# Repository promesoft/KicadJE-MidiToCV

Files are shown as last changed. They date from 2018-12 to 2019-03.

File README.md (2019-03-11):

# Kicad-MidiToCV
Midi to CV in Eurorack or as standalone

## Status - Rev B - Ongoing PCB layout and Sch update
Set on hold - MK2 is in progress ATM
## Status - Rev A Mounted - Midi code in progress
| Stage  | Detail | Status |
| --- | --- | --- |
| create material  | sch/pcb | produced Rev A  |
| | gerber | produced and uploaded RevA |
| production  | ordered  | OK |
|  | produced | OK |
|  | delivered | OK |
| ------------- | ------------- | ------------- |
| SOFTWARE | LFO | OK |
| SOFTWARE | MIDI MAP | OK - Stage 1 |
| SOFTWARE | CV | Ongoing |

## Preliminary validation
| Test  | Detail | Status |
| --- | --- | --- |
| Initial Inspection | Visual - Component Mounting | NOT OK |
| Initial Technical Test | Base operation | MIDI OUT NOT OK |
| | Knobs | OK |
| Initial Technical Test | MIDI IN | OK |
| Initial Technical Test | MIDI OUT | OK (to USB adapter) |
| Initial Product Test | MIDI IN/OUT MAPPER| OK |
| Initial Product Test | MIDI IN / CV OUT / GATE OUT| OK |
| Initial Product Test | LFO OUT| OK (use different pinout) |

## Secondary validation
| Test  | Detail | Status |
| --- | --- |--- |
| Product Test | MIDI IN/OUT| OUT - FAIL on Roland keyboard |
| Product Test | LFO on DIO6 and 9 with ext RC | OK ! |
| Quality | LFO | Very usable |
| Quality | MIDI IN | |
| Quality | MIDI to CV | |
| Quality | MIDI to GATE | |
| Long Term Product Test | MIDI IN |  |
| Long Term Product Test | CV OUT |  |
| Long Term Product Test | GATE OUT |  |
| Long Term Product Test | LFO OUT | OK |
### Issues and Notes
Please note that the PIN1 and PIN2 are GATE. This is note described clearly in http://www.doepfer.de/a100_man/a100t_e.htm and needs to be noted when soldering the IDC header or when cabling if a Pin header has been mounted.
 * The two pots on the breakout board are too close for adding a knob
 * The orientation of the pinheader for the MCP4725 module - if mounted incorrectly the magic smoke disappears
 * 0R could be replaced with SMD jumpers
 * Consider a 200 mA fuse for Vin and 50mA for +5V pwr
 * The mounting hole that is off center is not matching both boards
### Errata
 * Footprint of PJ-321 has too small drill holes (1mm) - major
 * Footprint of PJ-321 is too narrow in the rear end :) - minor issue
 * Midi out circuit is WRONG - Major
### Workarounds
* Midi out not working - PCB workaround mod partially possible for voltage controlled inputs.
 * --Remove GND around DIN pin 5 (bottom copper side)
 * --Cut GND track to DIN pin 5 (top copper side)
 * --Remove Q1, R6, R9
 * --Connect 220R THT to base pad on Q1
 * --Connect C and E on Q1
 * --Add GND wire to pin2 of MIDI out DIN
## Physical Construction
 - 100x100mm
 - Separate unit with no alteration
 - Optional split in 2 for eurorack mount mirrored config

## Vital Components
 - Arduino Nano - where the magic lives (remember to socket it to be able to reprogram it)
 - Jack connectors: PJ-321 (important for the footprint)
 - KY-40 Encoder module (important for the pullup, footprint and 3D alignment)
 - MCP4825 module - if chosen (important for CV out function - footprint needs to match)
 If these are chosen the last two CV jacks should be ommitted.
 - MCP4728 chip - if chosen (important for the last 2 CV out)

## MIDI Board Features
### Single board - MIDI I/O and MIDI to CV
The board can be used as is for a prototype development of MIDI to CV
### Split board Eurorack - MIDI I/O and MIDI to CV
The board can be devided in two and combined front to front with spacers for a MIDI to CV eurorack module.
### Base board Eurorack - MIDI I/O
If only MIDI features are required the base board can work without the IO section.

## Generic Board Features
### Split board Options
The main board (with the arduino) has a couple of headers that can be connected to a different interface board using I2C, Analogue Inputs and Digital I/O.
### Non MIDI board
The MIDI components can be omitted if the features does not require MIDI, like an LFO, VCO or ADSR circuit.

## Base Construction
Arduino Nano based Controller and MIDI decoder.

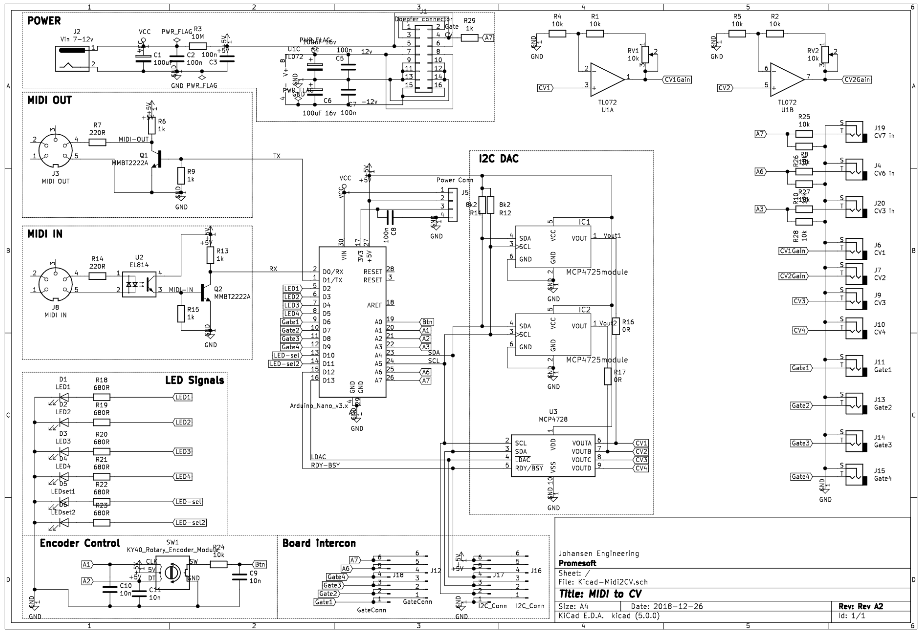
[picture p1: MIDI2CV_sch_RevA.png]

### MIDI In
MIDI In through a PC814 (or optional PC817) Optocoupler and into the RX pin on the Arduino

### Midi Out
Optional expansion

### Gate
Gate pins from Arduino

## CV Out
I2C Dac with 2 options
### I2C Dac - Option 1 - Two Single channel DAC
2x MCP4725 DAC 
### I2C Dac - Option 2 - One 4 channel DAC
1x MCP4728

# RevB
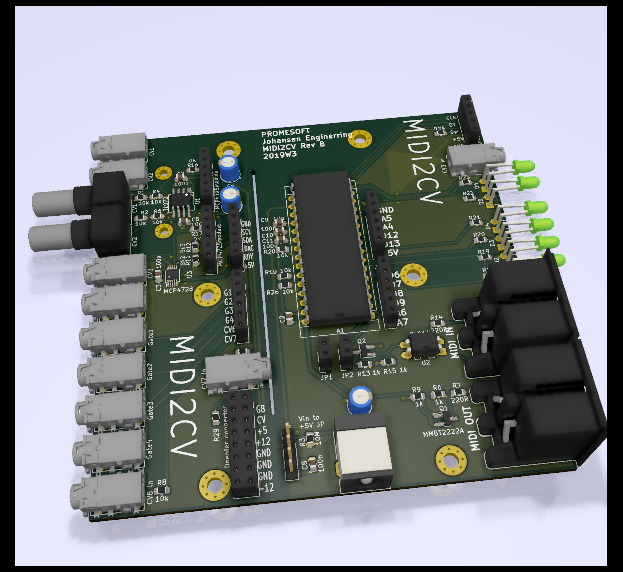
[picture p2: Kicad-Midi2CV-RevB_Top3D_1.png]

# RevA
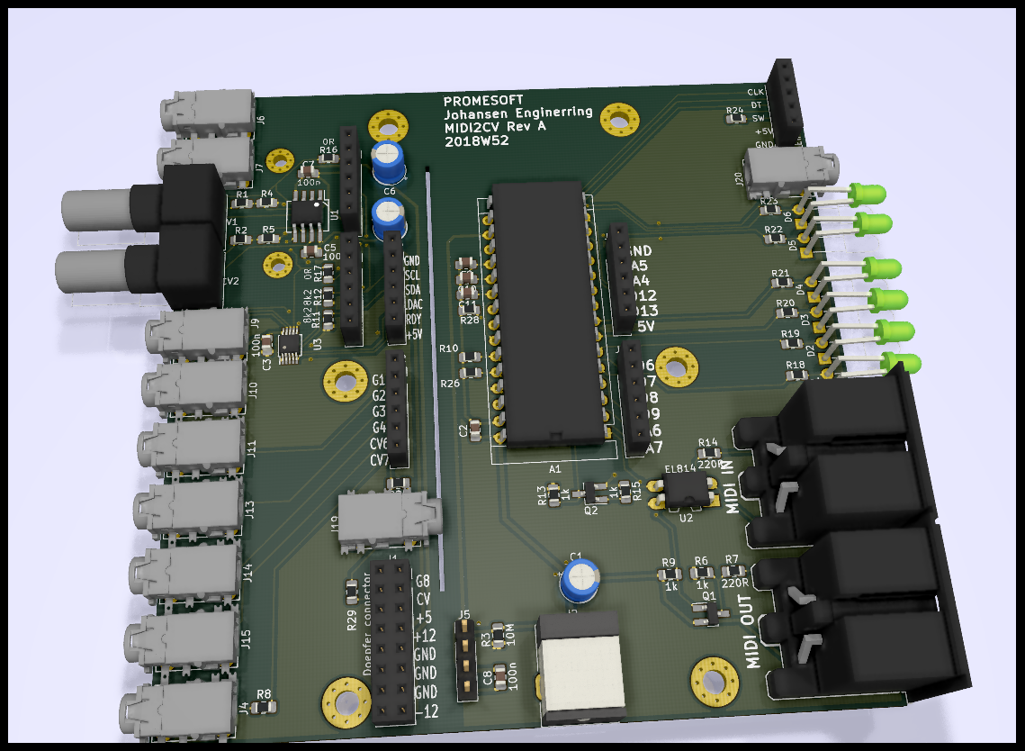
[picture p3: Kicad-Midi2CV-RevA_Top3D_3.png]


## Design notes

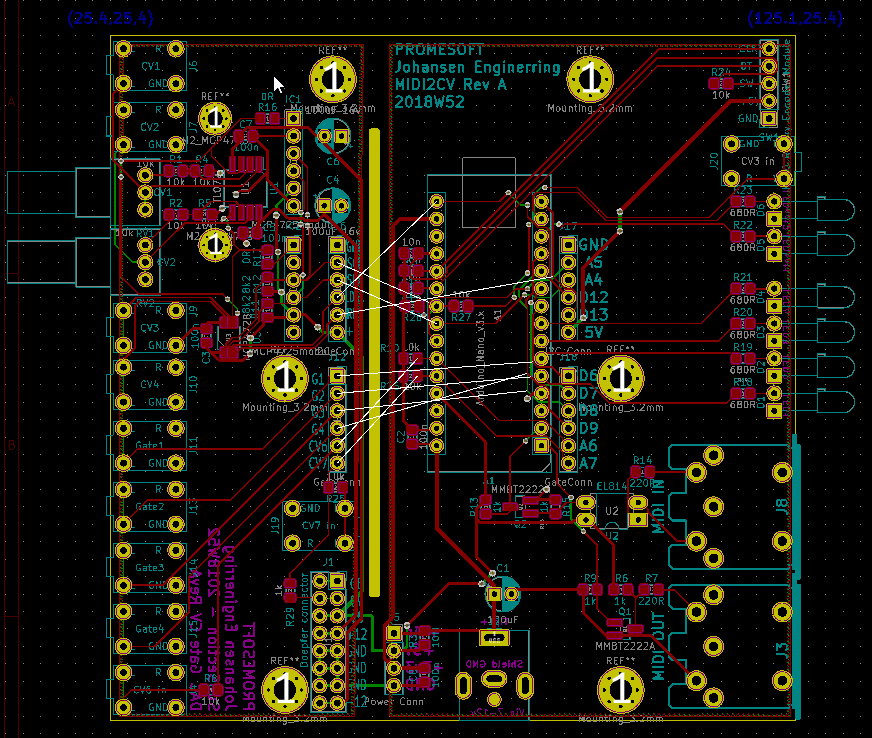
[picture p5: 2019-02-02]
2019-01-02 23_18_55-Window.png

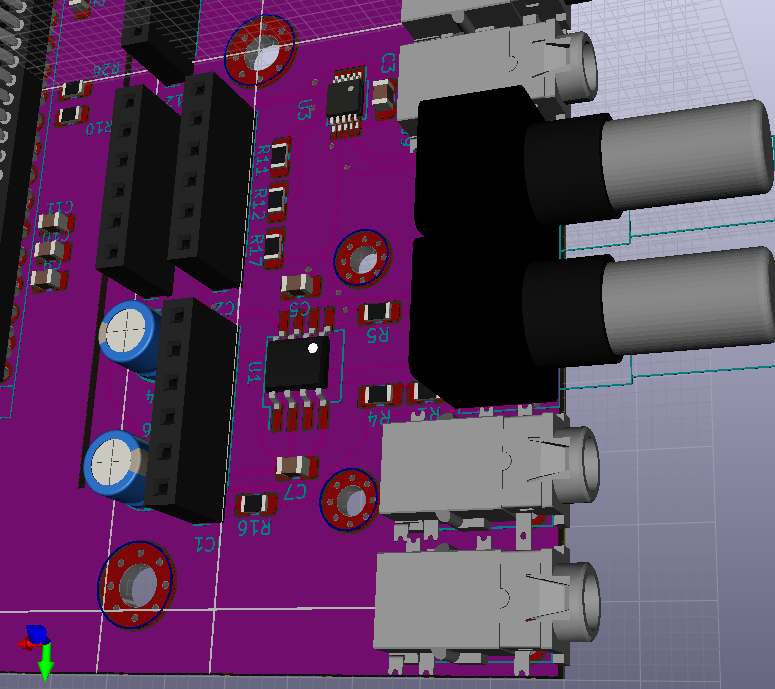
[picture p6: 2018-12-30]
RevA/MIDI2CV.png

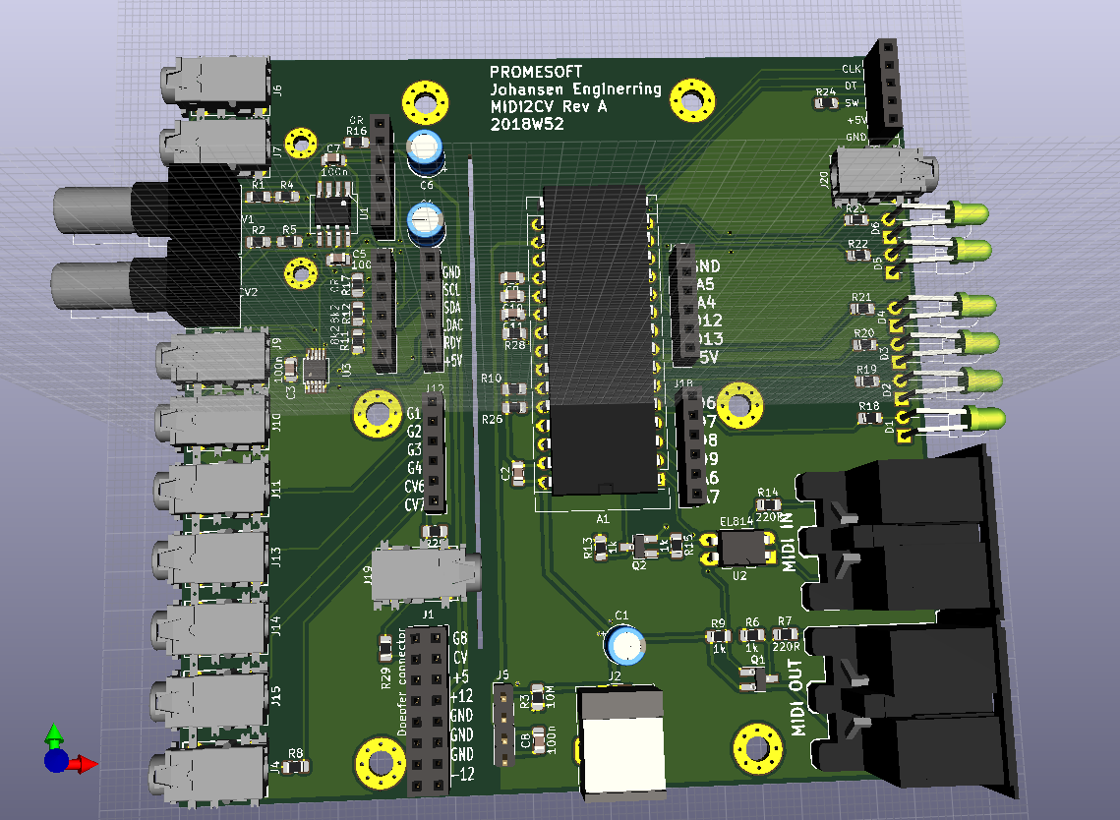
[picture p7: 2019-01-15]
RevA/Kicad-Midi2CV-RevA_Top3D.png

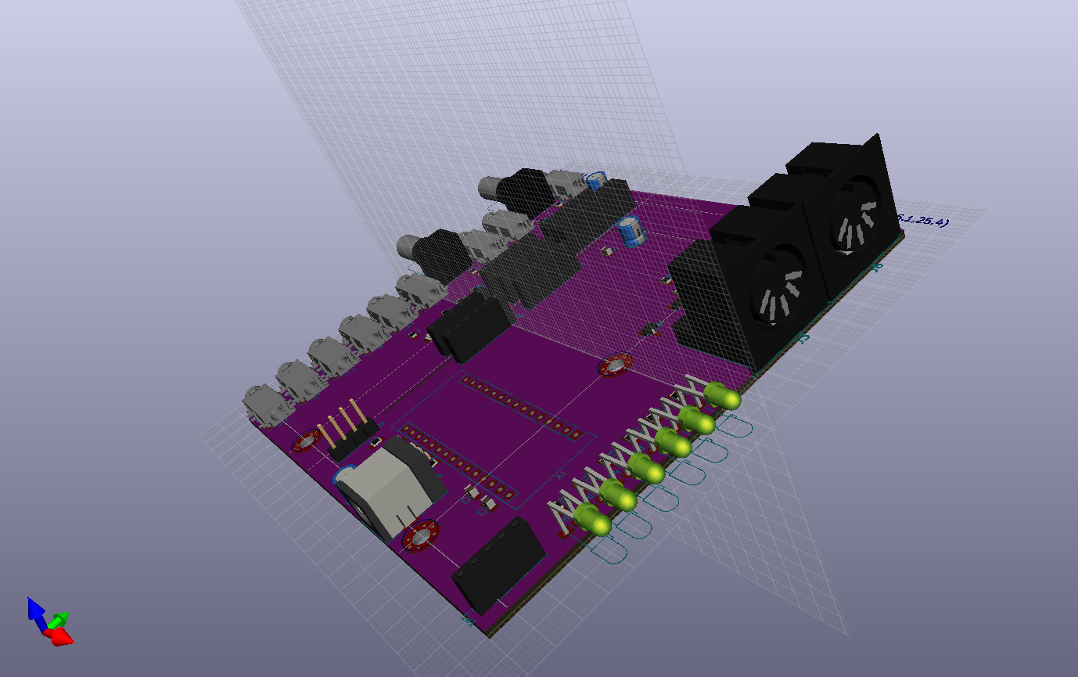
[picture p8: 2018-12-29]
RevA/Kicad-Midi2CV-3D.png

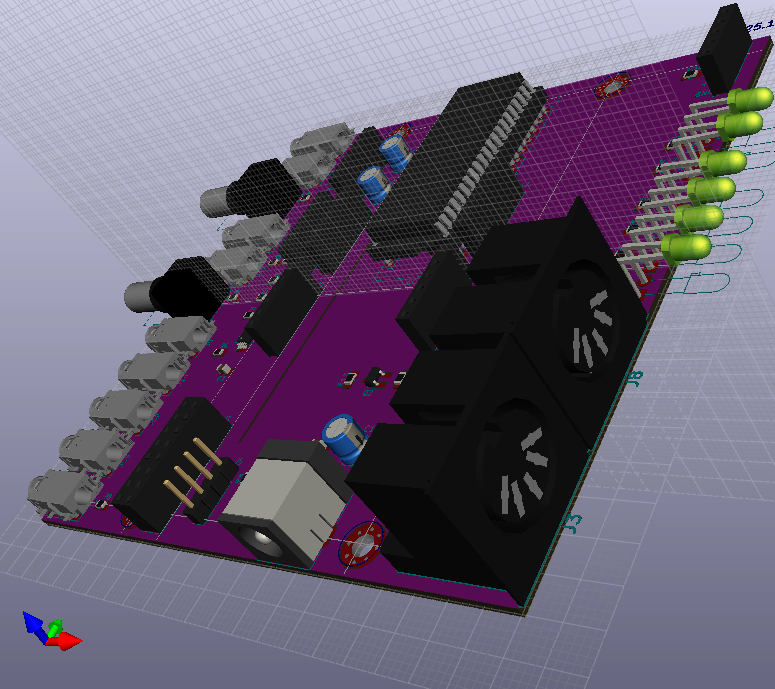
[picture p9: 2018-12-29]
RevA/Kicad-Midi2CV-3D2.png

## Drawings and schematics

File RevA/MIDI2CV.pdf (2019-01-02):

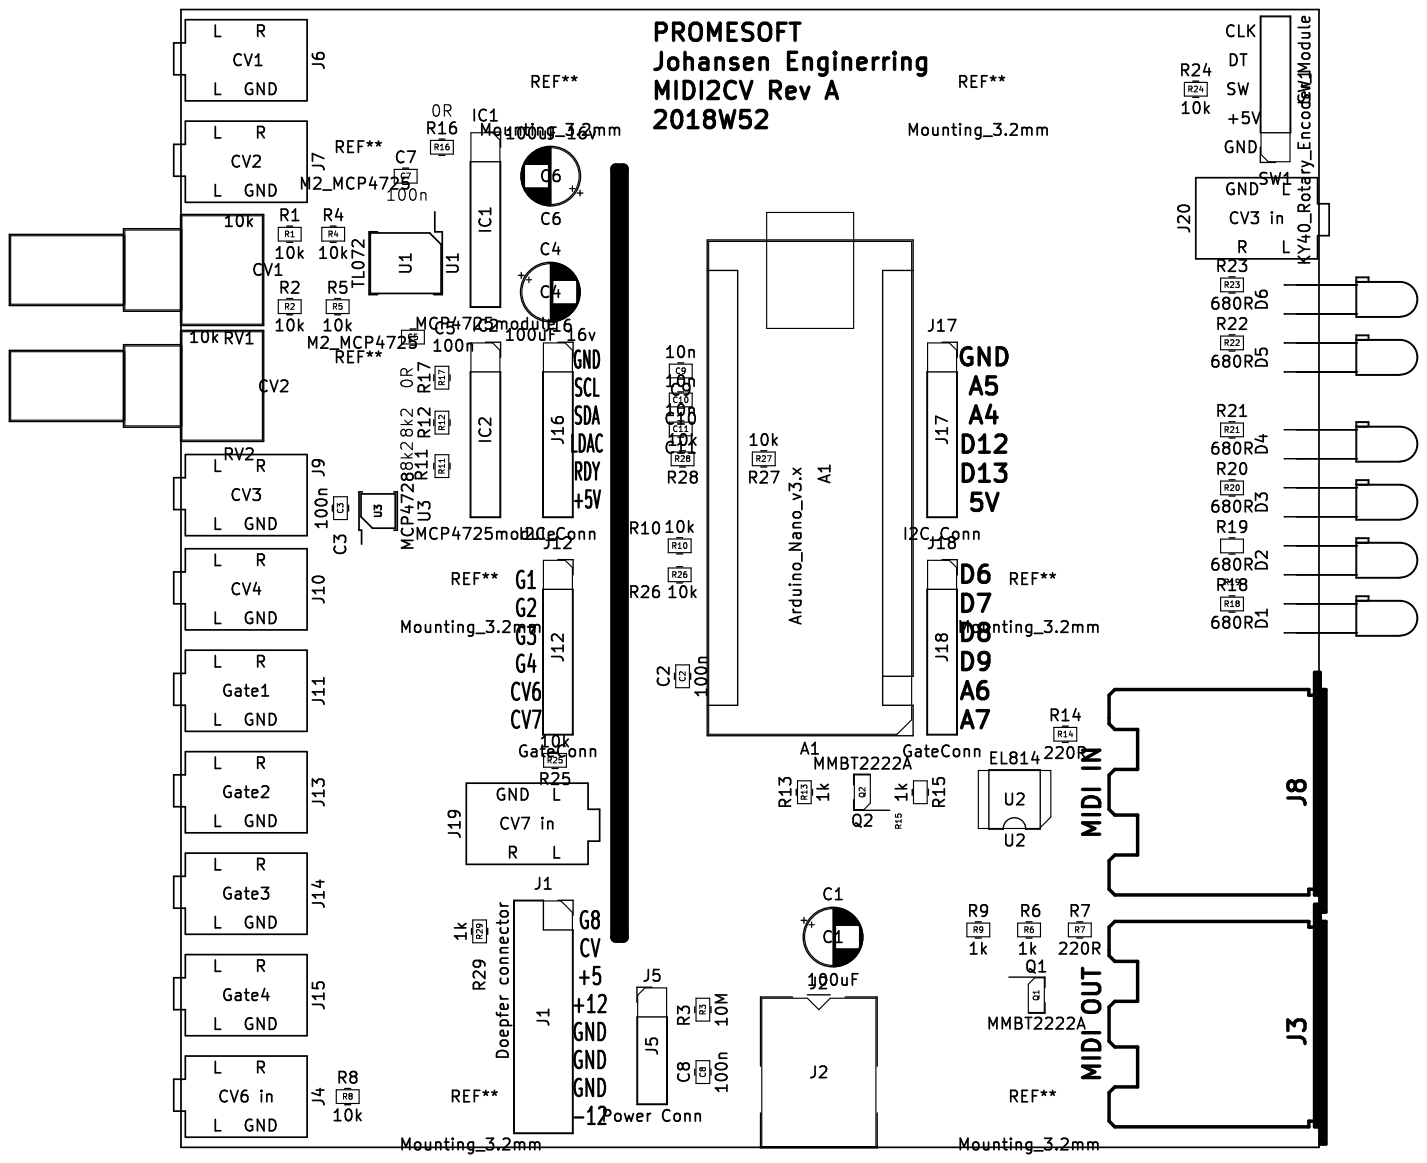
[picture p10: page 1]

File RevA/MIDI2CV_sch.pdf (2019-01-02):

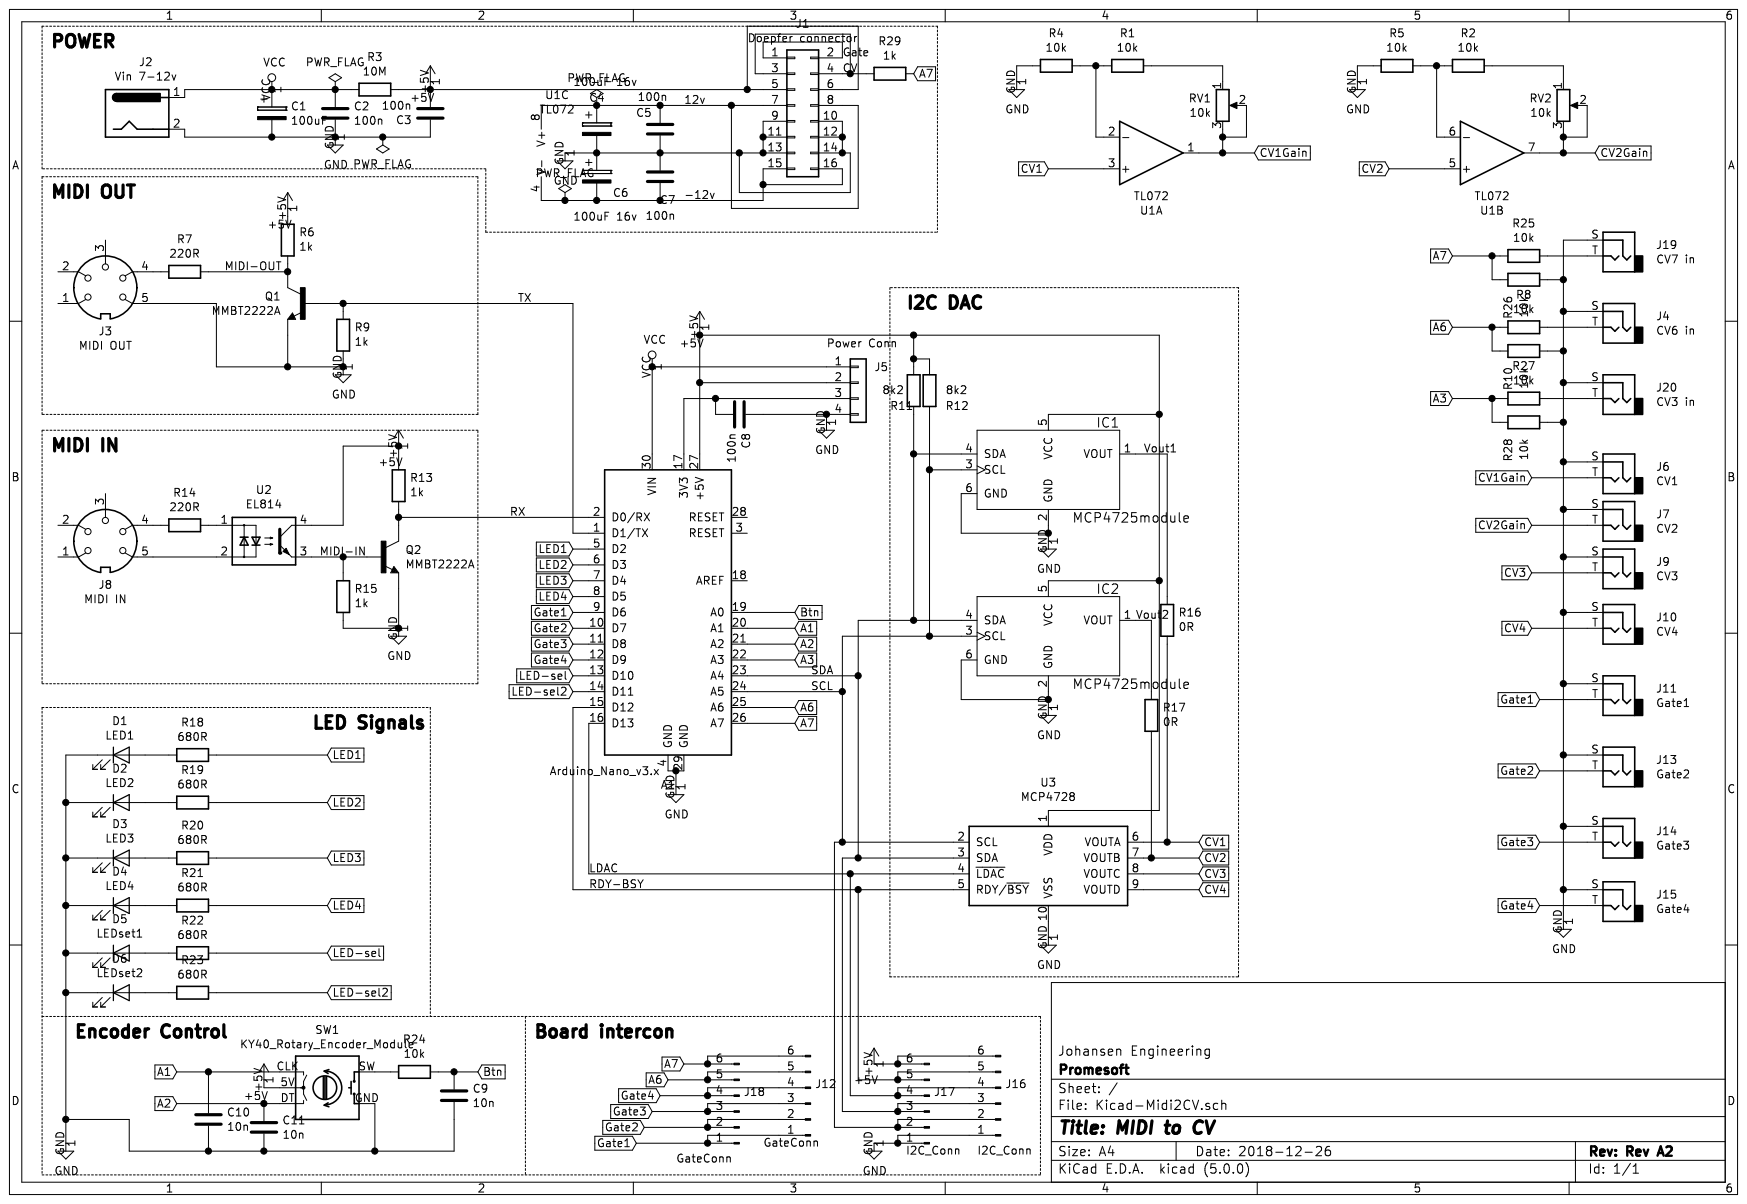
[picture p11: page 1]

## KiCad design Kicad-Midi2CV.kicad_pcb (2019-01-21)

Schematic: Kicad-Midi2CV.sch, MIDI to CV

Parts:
A1: Arduino_Nano_v3.x; Arduino_Nano
C1: 100uF; CP_Radial_D5.0mm_P2.50mm
C2, C3, C5, C7, C8, C10, C11: 100n; C_0805_2012Metric_Pad1.15x1.40mm_HandSolder
C4, C6: 100uF 16v; CP_Radial_D5.0mm_P2.50mm
C9: 10n; C_0805_2012Metric_Pad1.15x1.40mm_HandSolder
D1: LED1; LED_D3.0mm_Horizontal_O6.35mm_Z6.0mm
D2: LED2; LED_D3.0mm_Horizontal_O6.35mm_Z6.0mm
D3: LED3; LED_D3.0mm_Horizontal_O6.35mm_Z6.0mm
D4: LED4; LED_D3.0mm_Horizontal_O6.35mm_Z6.0mm
D5: LEDset1; LED_D3.0mm_Horizontal_O6.35mm_Z6.0mm
D6: LEDset2; LED_D3.0mm_Horizontal_O6.35mm_Z6.0mm
IC1, IC2: MCP4725module; PinSocket_1x06_P2.54mm_Vertical
J1: Doepfer connector; PinSocket_2x08_P2.54mm_Vertical
J2: Vin 7-12v; BarrelJack_CUI_PJ-063AH_Horizontal
J3: MIDI OUT; din-5
J4: CV6 in; AudioJack3StereoNarrow-PJ-321
J5: Power Conn; PinHeader_1x04_P2.54mm_Vertical
J6: CV1; AudioJack3StereoNarrow-PJ-321
J7: CV2; AudioJack3StereoNarrow-PJ-321
J8: MIDI IN; din-5
J9: CV3; AudioJack3StereoNarrow-PJ-321
J10: CV4; AudioJack3StereoNarrow-PJ-321
J11: Gate1; AudioJack3StereoNarrow-PJ-321
J12, J18: GateConn; PinSocket_1x06_P2.54mm_Vertical
J13: Gate2; AudioJack3StereoNarrow-PJ-321
J14: Gate3; AudioJack3StereoNarrow-PJ-321
J15: Gate4; AudioJack3StereoNarrow-PJ-321
J16, J17: I2C_Conn; PinSocket_1x06_P2.54mm_Vertical
J19: CV7 in; AudioJack3StereoNarrow-PJ-321
J20: CV3 in; AudioJack3StereoNarrow-PJ-321
JP1: Tx; PinSocket_1x02_P2.54mm_Vertical
JP2: Rx; PinSocket_1x02_P2.54mm_Vertical
Q1, Q2: MMBT2222A; SOT-23_Handsoldering
R1, R2, R4, R5, R8, R10, R24, R25, R26, R27, R28: 10k; R_0805_2012Metric_Pad1.15x1.40mm_HandSolder
R3: 10M; R_0805_2012Metric_Pad1.15x1.40mm_HandSolder
R6, R9, R13, R15, R29: 1k; R_0805_2012Metric_Pad1.15x1.40mm_HandSolder
R7, R14: 220R; R_0805_2012Metric_Pad1.15x1.40mm_HandSolder
R11, R12: 8k2; R_0805_2012Metric_Pad1.15x1.40mm_HandSolder
R16, R17: 0R; R_0805_2012Metric_Pad1.15x1.40mm_HandSolder
R18, R19, R20, R21, R22, R23: 680R; R_0805_2012Metric_Pad1.15x1.40mm_HandSolder
RV1, RV2: 10k; Potentiometer_Alps_RK097_Single_Horizontal
SW1: KY40_Rotary_Encoder_Module; KY-40-rotary-encoder-board
U1: TL072; AJ_SO-8_5.3x6.2mm_P1.27mm
U2: EL814; DIP-4_W7.62mm_LongPads
U3: MCP4728; MSOP-10_3x3mm_P0.5mm

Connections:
+5V: A1.27, C3.2, IC1.5, IC2.5, J1.5, J1.6, J5.2, J16.6, J17.6, R3.1, R6.2, R11.2, R12.2, R13.2, SW1.5V, U2.4, U3.1
/12v: C4.1, C5.2, J1.7, J1.8, U1.8 (V+)
/-12v: C6.2, C7.1, J1.15, J1.16, U1.4 (V-)
/CV: J1.3, J1.4, R29.2
/Gate: J1.1, J1.2
/LDAC: A1.16, J16.4, J17.4, U3.4
/MIDI-IN: Q2.1, R15.2, U2.3
/MIDI-OUT: Q1.3, R6.1, R7.1
/RDY-BSY: A1.15, J16.5, J17.5, U3.5
/SCL: A1.24, IC1.3, IC2.3, J16.2, J17.2, R12.1, U3.2
/SDA: A1.23, IC1.4, IC2.4, J16.3, J17.3, R11.1, U3.3
/TX: JP1.1, Q1.1, R9.2
/Vout1: IC1.1, R16.2
/Vout2: IC2.1, R17.2
A1: A1.20, C10.1, SW1.CLK
A2: A1.21, C11.1, SW1.DT
A3: A1.22, R27.2, R28.1
A6: A1.25, J12.5, J18.5, R8.2, R10.1
A7: A1.26, J12.6, J18.6, R25.2, R26.1, R29.1
Btn: A1.19, C9.1, R24.1
CV1: R16.1, U1.3 (+), U3.6
CV1Gain: J6.T, RV1.2, RV1.3, U1.1
CV2: R17.1, U1.5 (+), U3.7
CV2Gain: J7.T, RV2.2, RV2.3, U1.7
CV3: J9.T, U3.8
CV4: J10.T, U3.9
GND: A1.4, A1.29, C1.2, C2.2, C3.1, C4.2, C5.1, C6.1, C7.2, C8.1, C9.2, C10.2, C11.2, D1.1, D2.1, D3.1, D4.1, D5.1, D6.1, IC1.2, IC1.6, IC2.2, IC2.6, J1.9, J1.10, J1.11, J1.12, J1.13, J1.14, J2.2, J3.5, J4.S, J5.4, J6.S, J7.S, J9.S, J10.S, J11.S, J13.S, J14.S, J15.S, J16.1, J17.1, J19.S, J20.S, Q1.2, Q2.2, R4.2, R5.2, R9.1, R10.2, R15.1, R26.2, R28.2, SW1.GND, U3.10
Gate1: A1.9, J11.T, J12.1, J18.1
Gate2: A1.10, J12.2, J13.T, J18.2
Gate3: A1.11, J12.3, J14.T, J18.3
Gate4: A1.12, J12.4, J15.T, J18.4
LED1: A1.5, R18.1
LED2: A1.6, R19.1
LED3: A1.7, R20.1
LED4: A1.8, R21.1
LED-sel: A1.13, R22.1
LED-sel2: A1.14, R23.1
unnamed: A1.1, JP1.2
unnamed: A1.2, JP2.2
unnamed: A1.17, C8.2, J5.3
unnamed: D1.2, R18.2
unnamed: D2.2, R19.2
unnamed: D3.2, R20.2
unnamed: D4.2, R21.2
unnamed: D5.2, R22.2
unnamed: D6.2, R23.2
unnamed: J3.4, R7.2
unnamed: J4.T, R8.1
unnamed: J8.4, R14.2
unnamed: J8.5, U2.2
unnamed: J19.T, R25.1
unnamed: J20.T, R27.1
unnamed: JP2.1, Q2.3, R13.1
unnamed: R1.1, RV1.1
unnamed: R1.2, R4.1, U1.2 (-)
unnamed: R2.1, RV2.1
unnamed: R2.2, R5.1, U1.6 (-)
unnamed: R14.1, U2.1
unnamed: R24.2, SW1.SW
VCC: A1.30, C1.1, C2.1, J2.1, J5.1, R3.2

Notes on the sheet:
MIDI IN
LED Signals
Encoder Control
I2C DAC
POWER
MIDI OUT
Board intercon

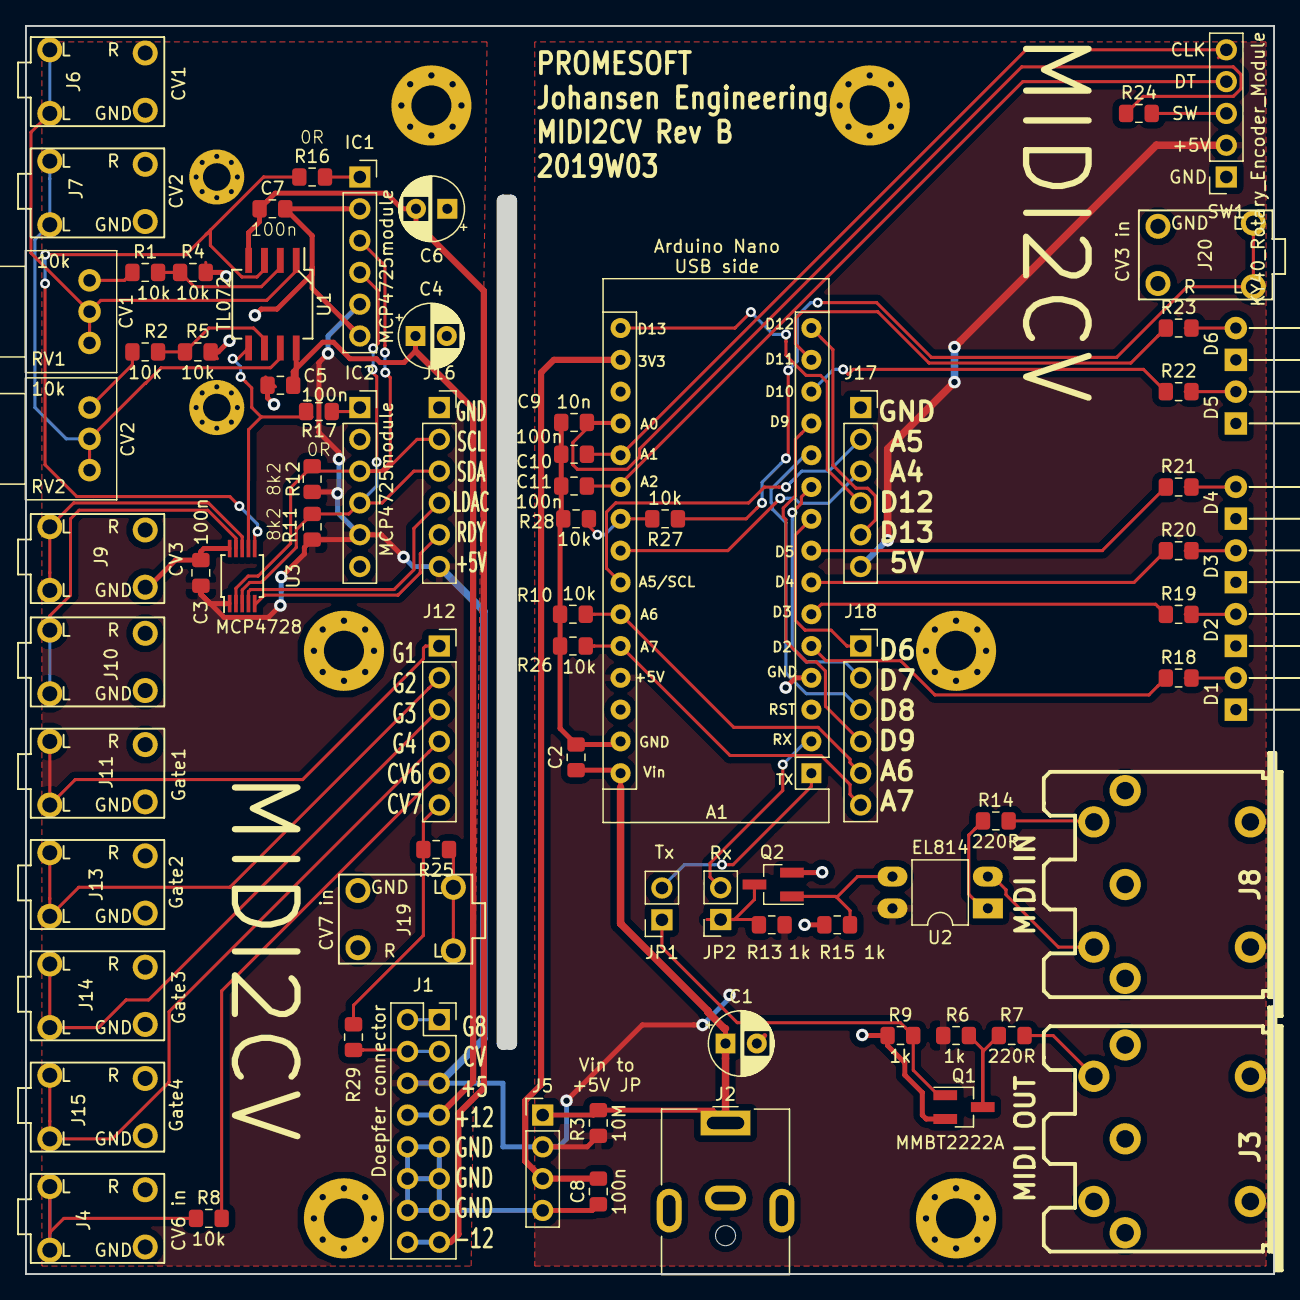
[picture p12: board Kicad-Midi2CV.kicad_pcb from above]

Board: 2 copper layers, 99.7 x 99.7 mm, 79 parts (0 on the bottom side), 60 nets.

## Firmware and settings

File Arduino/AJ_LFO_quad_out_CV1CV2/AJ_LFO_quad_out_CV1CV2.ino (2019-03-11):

/* 
 * Wavetable LFO inspiration: 
 * https://www.muffwiggler.com/forum/viewtopic.php?t=169706&sid=4b0d7d4af599d0df3e7b6fc29ece21b8 
 *  
 */ 

#include "wavetable.h";
//#include "globals.h";
#include "midi.h";


/* =====================================================
==============INIT DATA STRUCTURES======================
======================================================*/  
void setupDataStruct(){
   for (int i=0; i <= 3; i++){
     for (int j=0; j <= 3; j++){
      LEDData[i][j]=false;
     }
     MIDI_CH[i] = EEPROM.read(i);
     if (MIDI_CH[i] > 15) MIDI_CH[i] = 0;
      updateLEDValue(MIDI_CH[i], i);
      encoder[i] = MIDI_CH[i] << 2;
   }
}
/* =====================================================
==============SETUP=====================================
======================================================*/  
void setup() {  
  Serial.begin(38400);
  Serial.println();
  Serial.println("");
  Serial.println(F(__FILE__));
  Serial.print(F("Build date: "));
  Serial.println(F(__DATE__));
  delay(50);  
  setupDataStruct();
  
/* ===========Encoder Setup=============================*/
  pinMode(SWpin, INPUT);
  pinMode(Apin, INPUT);
  pinMode(Bpin, INPUT);
  // Enable internal pull-up resistors
  digitalWrite(SWpin, HIGH);
  digitalWrite(Apin, HIGH);
  digitalWrite(Bpin, HIGH);

/* ===========LED Setup=================================*/
  pinMode(LED1, OUTPUT);
  pinMode(LED2, OUTPUT);
  pinMode(LED3, OUTPUT);
  pinMode(LED4, OUTPUT);
  pinMode(LEDsel, OUTPUT);
  pinMode(LEDsel2, OUTPUT);
  
  digitalWrite(LED1, HIGH);
  digitalWrite(LED2, HIGH);
  digitalWrite(LED3, HIGH);
  digitalWrite(LED4, HIGH);
  delay(150);

  updateLED();

/* =========Saw wave for table 1 =======================*/
/*  for(int i=0; i<256; i++) {                                  // Precalculates a simple Tri-Wavetable in the first wavetable. Delete these 2 for-loops if you have filled up your wavetables 
    waveTable[1][i]=i; 
    }*/   
/* =========Triangle wave for table 2===================*/
/*  for(int i=0; i<128; i++) {                                  // Precalculates a simple Tri-Wavetable in the first wavetable. Delete these 2 for-loops if you have filled up your wavetables 
    waveTable[2][i]=i*2; 
    } 
  for(int i=0; i<128; i++)  { 
    waveTable[2][i+128]=256-i*2; 
  } 
  waveTable[2][128]=255;*/
/* =========Step 8 wave table 3=========================*/
/*  for(int i=0; i<256; i++) {                                  // Precalculates a simple Tri-Wavetable in the first wavetable. Delete these 2 for-loops if you have filled up your wavetables 
    waveTable[3][i]=(i&0b11100000); 
    }*/ 
/* =========Setup LFO Output pins=======================*/
  pinMode(PWM1, OUTPUT);                                           // Sets Pin PWM1 PWM-Output 
  pinMode(PWM2, OUTPUT);                                           // Sets Pin PWM2 PWM-Output 
  pinMode(Square, OUTPUT);                                          // Pin as LED for Tempo and as a square-LFO 
  pinMode(InvSquare, OUTPUT);                                          // Pin as LED for Tempo and as a inverted square-LFO 
  
/* =========Enable interrupt on A0,1,2==================*/
  // 1. PCIE1: Pin Change Interrupt Enable 1
  PCICR =  0b00000010; 
  // Enable Pin Change Interrupt for A0, A1, A2
  PCMSK1 = 0b00000111; 

//Safety before MIDI takes over so the arduino can be reprogrammed
  delay(800); 
/* =====================================================*/
  setupMidi();
} 

/* =====================================================
==============MAIN LOOP=================================
======================================================*/  
void loop() { 
  checkencoder();                  //Check encoder and update values

  updateLED();                     //LED on for active state    
  midiRead();
  updateLEDValue(MIDI_CH[0], 0); //Update current midi chan for state 0
  clearLED();                      //LED off (dim light)

  updatewave();
}

/* =====================================================
==============Update LED's based on LED Values==========
======================================================*/ 
char getWaveSample(unsigned int PWMshape){
    switch (PWMshape) {
      case 1:
        PWMdata = tableStep;
        // Saw wave for shape 1
        break;
      case 2:
        PWMdata = 256-tableStep;
        // Inv Saw wave for shape 2
        break;
      case 3:
        //Triangle wave for shape 3
        PWMdata = tableStep * 2;
        if (tableStep > 127) PWMdata = 256-(2*(tableStep-127)); 
        break;
      case 4: // Step 4
        PWMdata = (tableStep&0b11000000)+64;
        break;
      case 5: // Step 8
        PWMdata = (tableStep&0b11100000)+32;
        break;
      case 6: // Step 16
        PWMdata = (tableStep&0b11110000)+16;
        break;
      case 7: // Step 32
        PWMdata = (tableStep&0b11111000)+8;
        break;
      case 8: // Step 4 + noise
        PWMdata = random(120) * (tableStep>>6);
        break;
      case 9: // Step 8 + noise
        PWMdata = random(60) * (tableStep>>5);
        break;
      case 10: // noise
        PWMdata = random(255);
        break;
      case 11: // noise
        PWMdata = random(128) + tableStep;
        break;
      case 12: // ramp and noise
        if (tableStep < 127 ) {
          PWMdata = 2 * tableStep;
        }
        else {
          PWMdata = random(255);
        }
        break;
      case 13: // half ramp
        if (tableStep < 127 ) {
          PWMdata = 2 * tableStep;
        }
        else {
          PWMdata = 0;
        }
        break;
      case 14: // 25% duty cycle
        if (tableStep < 63 ) {
          PWMdata = 255;
        }
        else {
          PWMdata = 0;
        }
        break;
      case 15: // pulse 6% duty cycle
        PWMdata = 0;
        if (tableStep < 64) {
          PWMdata = 255;
        }
        if (tableStep > 128) {
          if (tableStep < 192) {
            PWMdata = 255;
          }
        }
        break;
      default:
        // Sine wave for shape 0
        PWMdata = waveTable[tableStep];
        break;
    }
    return PWMdata;
}
/* =====================================================
==============Update Wave data pointer==================
======================================================*/ 
void updatewave(){
  if ( millis() >= (lastwaveupdate+delayTime) ){
    lastwaveupdate = millis();
    tableStep++;                                                // Jumps to the next step. 
                                                                /* tableStep is an 8-Bit unsigned integer, 
                                                                so it can only store a value between 0 and 255 and will 
                                                                automatically "overflow" and go back to 0 when it gets 
                                                                bigger than 255, which is the lenght of the lookup table. 
                                                                 */ 
  /*  Serial.print(F("Delay time: "));
    Serial.print(MIDI_CH[3]<<1);
    Serial.println(F(" "));*/
    delayTime =  32 - (MIDI_CH[3]<<1);                                 // values from 0 to 15 shifted up 1 
                                                                // multiplied by 2 as delay from sample to sample 
  /* ===========Update Square Output======================*/
    if(tableStep<128) {                                           // Turn LED on for first half of the cycle, indicate Tempo 
      digitalWrite(Square, HIGH); 
      digitalWrite(InvSquare, LOW); 
    } 
    else {                                                        // Turn it off for the second half 
      digitalWrite(Square, LOW); 
      digitalWrite(InvSquare, HIGH); 
    } 
  /* ===========Update PWM1 Output========================*/
    PWMdata = getWaveSample(MIDI_CH[2]);

  //  analogWrite(PWM1, waveTable[PWMshape1][tableStep]);              // Writes the value at the current step in the table to Pin 5 as PWM-Signal.  
    analogWrite(PWM1, PWMdata);
  
  /* ===========Update PWM2 Output========================*/
    PWMdata = getWaveSample(0b00001111&(MIDI_CH[2]+4));
  //  analogWrite(PWM2, waveTable[PWMshape2][tableStep]);              // Writes the value at the current step in the table to Pin 5 as PWM-Signal.  
     analogWrite(PWM2, PWMdata);
  }
}

/* =====================================================
==============Check encoder interrupt===================
======================================================*/ 
void checkencoder(){
  if (left){
    left = false;
    if (encoder[state] != 0) encoder[state]--; // Decrement if not 0
    if (state < 4) {
      if(((MIDI_CH[state]=encoder[state] >> 2) == 0) && state == 2) MIDI_CH[state]=16;
      updateLEDValue(MIDI_CH[state], state);
      EEPROM.write(state, MIDI_CH[state]);
    }
  }
  if (right){
    right = false;
    if (encoder[state] < 0x3f) encoder[state]++;
    if (state < 4) {
      MIDI_CH[state]=encoder[state] >> 2;
      updateLEDValue(MIDI_CH[state], state);
      EEPROM.write(state, MIDI_CH[state]);
    }
  }
  if (button){
    button = false;    
    buttoncnt++;
    buttoncnt = buttoncnt & B00000111;
    state = buttoncnt >> 1;
    }
}
/* =====================================================
==============Update LED Values based on input==========
======================================================*/ 
void updateLEDValue(unsigned int nibble,unsigned int updstate)
{
  if (nibble >= 0x10) nibble = 0x0f;
  else (nibble = nibble & 0x0f);
  if (nibble & 0x01){
//    LED1Data = true;
    LEDData[updstate][0] = true;
  }
  else {
//    LED1Data = false;
    LEDData[updstate][0] = false;
  }
  if (nibble & 0x02){
//    LED2Data = true;
    LEDData[updstate][1] = true;
  }
  else {
//    LED2Data = false;
    LEDData[updstate][1] = false;
  }
  if (nibble & 0x04){
//    LED3Data = true;
    LEDData[updstate][2] = true;
  }
  else {
//    LED3Data = false;
    LEDData[updstate][2] = false;
  }
  if (nibble & 0x08){
//    LED4Data = true;
    LEDData[updstate][3] = true;
  }
  else {
//    LED4Data = false;
    LEDData[updstate][3] = false;
  }

}
/* =====================================================
==============Update LED's based on LED Values==========
======================================================*/ 
void updateLED(){
  digitalWrite(LED1, LEDData[state][0]);
  digitalWrite(LED2, LEDData[state][1]);
  digitalWrite(LED3, LEDData[state][2]);
  digitalWrite(LED4, LEDData[state][3]);
  delay(1);
  digitalWrite(LEDsel, state & B00000001);
  digitalWrite(LEDsel2, state & B00000010);
}

void clearLED(){
  digitalWrite(LED1, LOW);
  digitalWrite(LED2, LOW);
  digitalWrite(LED3, LOW);
  digitalWrite(LED4, LOW);
  digitalWrite(LEDsel, LOW);
  digitalWrite(LEDsel2, LOW);
}

/* =====================================================
==============Encoder change interrupt==================
======================================================*/  

ISR (PCINT1_vect) {
// If interrupt is triggered by the button
  boolean SW_val = digitalRead(SWpin);
  if (SW_val != SW_old) {
    SW_old = SW_val;
    button = true;}

// Else if interrupt is triggered by encoder signals
  else {
    
    // Read A and B signals
    boolean A_val = digitalRead(Apin);
    if (A_val != A_old) {
      A_old = A_val;
      if (A_val^B_old) {
        right = true;
      }
      else {
        left = true;
      }
    }
    else {
      boolean B_val = digitalRead(Bpin);
      B_old = B_val;
      if (A_val^B_val) {
        left = true;
      }
      else {
        right = true;
      }
    }
  }
}

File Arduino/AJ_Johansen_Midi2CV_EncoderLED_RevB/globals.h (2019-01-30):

/* -----------------------------------------------
 *  EEPROM DATA STRUCTURE
 *  
 *  0000:0003 MIDI_CH[state]
 *  
 *  
 *  
 * -----------------------------------------------
 */
#include <EEPROM.h>
/* -----------------------------------------------
 *  GLOBAL DEFINES
 * -----------------------------------------------
 */
#define SWpin A0 //add 10nF to GND for debounce (not essential
#define Apin A1 //add 47nF/100nF to GND for debounce
#define Bpin A2 //add 47nF/100nF to GND for debounce
#define CV3in A3
#define SDA A4
#define SCL A5
#define CV6in A6
#define CV7in A7

#define LED1 2
#define LED2 3
#define LED3 4
#define LED4 5
#define LEDsel 10
#define LEDsel2 11

#define Gate1 6
#define Gate2 7
#define Gate3 8
#define Gate4 9

#define RDY-BSY 12
#define LDAC 13

/* -----------------------------------------------
 *  GLOBAL VAR
 * -----------------------------------------------
 */
boolean A_old=0, B_old=1, SW_old=0;
boolean left = false, right = false, button = false;

//Structure for keeping MIDI CH data for LED
boolean LEDData[4][4]; //(see state)

boolean LEDSelData = false, LEDSel2Data = false; 
unsigned int encoder[4], buttoncnt = 0;
unsigned int state = 0; //State 00 = MidiDataInChannel - 01 = MIDI CH in select - 10 = MIDI CH OUT select - 11 = MIDI CH 2 CV select

//byte midi_channel=4;
//Structure for keeping MIDI CH data for processing
byte MIDI_CH[4]; //(see state)


/* -----------------------------------------------
 *  PROTOTYPES
 * -----------------------------------------------
 */
void MyHandleNoteOn(byte channel, byte pitch, byte velocity);
void MyHandleNoteOff(byte channel, byte pitch, byte velocity);

/*void checkencoder();
//void updateLEDValue(unsigned int nibble,unsigned int updstate);
void updateLED();
void clearLED();
*/

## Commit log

2018-12-20 Project Initiated
    Core components added
    Initial wiring performed
    Grid 50mil
    [Kicad-Midi2CV.kicad_pcb, Kicad-Midi2CV.sch]
2018-12-20 GND and LED
    GND added
    MIDI CH LED indicators added
    [Kicad-Midi2CV.sch]
2018-12-20 I2C
    Power and pullup
    [Kicad-Midi2CV.sch]
2018-12-20 reorganize
    boxes around functions
    [Kicad-Midi2CV.sch]
2018-12-20 MIDI pinout
    correct
    [Kicad-Midi2CV.sch]
2018-12-20 DIN-5 footprint
    added from http://smisioto.no-ip.org/elettronica/kicad/kicad-en.htm
    [Kicad-Midi2CV.sch]
2018-12-20 Channel select
    Rotary encoder added for MIDI channel select
    [Kicad-Midi2CV.sch]
2018-12-20 Footprints
    Cap, BJT, Conn, Etc
    [Kicad-Midi2CV.sch]
2018-12-21 Footprints
    footprint PL814
    [Kicad-Midi2CV.sch, _saved_Kicad-Midi2CV.sch]
2018-12-22 mini in
    adj
    [Kicad-Midi2CV.sch, _saved_Kicad-Midi2CV.sch]
2018-12-25 Power +5V
    Misc power and resistors near encoder
    [Kicad-Midi2CV.sch]
2018-12-25 misc
    misc
    [Kicad-Midi2CV.sch]
2018-12-26 Power redraw
    Redraw power
    [Kicad-Midi2CV.sch]
2018-12-26 Jack
    PJ398SM x2 jack
    [Kicad-Midi2CV.sch]
2018-12-26 LED tag
    Labels for LED, button, encoder and Gates
    [Kicad-Midi2CV.sch]
2018-12-26 Multi IO
    Gate3/4
    Encoder to A0, A1, A2
    A3 as input
    LED sel2
    [Kicad-Midi2CV.sch]
2018-12-26 Rev A ------- before check
    9 Jacks attached
    Slight rearrange
    [Kicad-Midi2CV.sch]
2018-12-26 Rev A2 - prior to footprint
    CV1 and CV2 with gain adjustment
    [Kicad-Midi2CV.sch]
2018-12-26 MIDI Out
    Misc Cleanup
    [Kicad-Midi2CV.sch]
2018-12-26 Footprints
    Rotary encoder should be replaced...
    [Kicad-Midi2CV.sch]
2018-12-27 PCB RevA - need new footprints and update 3D
    Board split in 2
    [Kicad-Midi2CV.kicad_pcb]
2018-12-28 Replace PJ301 w PJ321
    [Kicad-Midi2CV.sch]
2018-12-28 Jack I/O
    Label jacks
    Voltage div on CV in / A3
    [Kicad-Midi2CV.kicad_pcb, Kicad-Midi2CV.sch]
2018-12-28 Names to remaining IO
    MIDI
    LED
    Pots are kept as RV1 and RV2 as it matches CV1 and CV2
    Front panel rearranged
    [Kicad-Midi2CV.kicad_pcb]
2018-12-28 PCB misc
    [Kicad-Midi2CV.kicad_pcb, _saved_Kicad-Midi2CV.sch]
2018-12-28 PCB
    Misc - minor
    [Kicad-Midi2CV.kicad_pcb]
2018-12-29 Fixed Analog voltage
    Encoder module replace
    PCB reorganize
    Added Analogue supply - not done
    changed Jacks
    etc
    [Kicad-Midi2CV.kicad_pcb, Kicad-Midi2CV.sch, _saved_Kicad-Midi2CV.sch]
2018-12-29 Board interconnectors
    Gate and I2C signals prepared
    [Kicad-Midi2CV.sch]
2018-12-29 organizing PCB placement
    [Kicad-Midi2CV.kicad_pcb, _saved_Kicad-Midi2CV.sch]
2018-12-29 Interconn footprint adj
    [Kicad-Midi2CV.kicad_pcb]
2018-12-29 Update _saved_Kicad-Midi2CV.sch
    Swap SCL and SDA in board interconnector
    [_saved_Kicad-Midi2CV.sch]
2018-12-29 Reorganize PCB
    make sure the board assembles when sandwiched
2018-12-29 Analogue card routed - no GND
    [Kicad-Midi2CV.kicad_pcb, Kicad-Midi2CV.sch, _saved_Kicad-Midi2CV.sch]
2018-12-30 AJ_SO8 pad for Op Amp
    [Kicad-Midi2CV.kicad_pcb, Kicad-Midi2CV.sch, _saved_Kicad-Midi2CV.sch]
2018-12-30 Initial routing on CPU side
    [Kicad-Midi2CV.kicad_pcb]
2018-12-30 Before planes...
    [Kicad-Midi2CV.kicad_pcb]
2018-12-30 RevA PCB
    [Kicad-Midi2CV.kicad_pcb]
2018-12-30 PCB Final Trim
    Silk adj:
    Text adjustments
    Label board x2
    Label headers
    Add values to resistors on silk
    Power lanes beefed up (0,5 or 0,6) when long or feed.
    [Kicad-Midi2CV.kicad_pcb, _saved_Kicad-Midi2CV.sch]
2018-12-30 Gerber
    Gerber and Drill for JLC
    [Kicad-Midi2CV-B.Cu.gbr, Kicad-Midi2CV-B.Mask.gbr, Kicad-Midi2CV-B.Paste.gbr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]
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2019-01-09 Update README.md
    Split and single board
2019-01-21 RevA Archived - RevB Initiated
    PJ-321 footprint drill increased from 1mm to 1,2mm and rear holes narrower
    [Kicad-Midi2CV-B.Cu.gbr, Kicad-Midi2CV-B.Mask.gbr, Kicad-Midi2CV-B.Paste.gbr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]
2019-01-21 R and C Labels on analogue side
    [Kicad-Midi2CV.kicad_pcb]
2019-01-21 Rev B PCB - SCH - Images
    [Kicad-Midi2CV-B.Cu.gbr, Kicad-Midi2CV-B.Mask.gbr, Kicad-Midi2CV-B.Paste.gbr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]
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2019-01-24 Iteration2 - XPS (no compile? no test!)
    Update filename - restructure LED out - select LED counter
2019-01-26 Arduino - Sel and Sel2 works
    only compiles on windows store edition - 1.8.8 complains abt ISR (PCINT1_vect) {
2019-01-27 Arduino code - separate states for all 4 led sections
2019-01-27 Arduino - Midi input - show channel on LED state 0
2019-01-29 Arduino - Mapping Incomming MIDI channel to state1 channel
2019-01-29 Arduino - Initial working prototype
    :oD
    [_saved_Kicad-Midi2CV.sch]
2019-01-30 Updated Midi out
    initial failsafe with lots of extra optional components
    [Kicad-Midi2CV.sch, _saved_Kicad-Midi2CV.sch]
2019-01-30 Overengineered MIDI out
    To accomodate for almost all eventialities the MIDI out now consists of 10 resistors and one transistor....A NO jumper has been installed for the GND to shield of the DIN conn.
    [_saved_Kicad-Midi2CV.sch]
2019-01-30 MIDI out JP3 footprint changed to closed JP
    [Kicad-Midi2CV.sch, _saved_Kicad-Midi2CV.sch]
2019-01-31 New Front plate design for RevB (MK2.1)
2019-02-10 Arduino LFO
    [_saved_Kicad-Midi2CV.sch]
2019-02-11 Arduino - dual LFO sine+triangle
    [_saved_Kicad-Midi2CV.sch, sine.csv]
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2019-02-15 Arduino - Mem optimized for LFO Quad out
    Quad out: 2 PWM shapes out, square and inv square out
2019-02-15 Arduino - Quad LFO Working nicely :)
    Tested with VCF and DRone
2019-03-11 Arduino - CV control ch1 - Gate control ch1
    [Kicad-Midi2CV.sch]
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
